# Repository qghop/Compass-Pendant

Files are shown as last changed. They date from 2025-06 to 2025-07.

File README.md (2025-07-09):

# Compass-Pendant
WIP - Creating a Pendant with LEDs and a Compass Module on a custom PCB

## Design Goals and Inspiration

The main design goal from the beginning was to create a unique piece of jewlery, from a Custom PCB with real-world functional components. 

Several purposes were ideated for this purpose. I initially wanted to create a GPS Logging Device to track my position, an idea I was first enamored by with [BOTW's Hero's Path Mode](https://www.youtube.com/watch?v=YSooSC6LfSU), and without giving my position data away to, or relying upon, a huge company like Google Maps' Timeline feature requires. I couldn't figure out a way to keep all the components small for this idea, so it was shelved, though I implemented a similar feature in my [Apple Photos Analysis Project](https://github.com/qghop/Apple-Photos-Analysis).

Different sensors, chips, and general designs were considered, but eventually using a Coin Cell Battery, an ATmega328P, and an I2C Magnetometer were chosen for ease of implementing, in both wiring and programming. 

The whole project was heavily inspired by the work of [Mitxela](https://mitxela.com/), especially his [UV Protection Amulet](https://www.youtube.com/watch?v=JhNMeJZ8Ll0) and [Fluid Simulation Pendant](https://www.youtube.com/watch?v=jis1MC5Tm8k). The header for chip programming was taken from the [KeyChainino](https://www.keychainino.com/) project, thanks to [upir](https://www.youtube.com/watch?v=Zsum_6dWfVU) for their video on the device. Additional thanks to the hundreds of KiCad tutorials used to build the PCB.

## Media

### V1

Working Compass Video (https://www.youtube.com/watch?v=5i10F70vsIM)

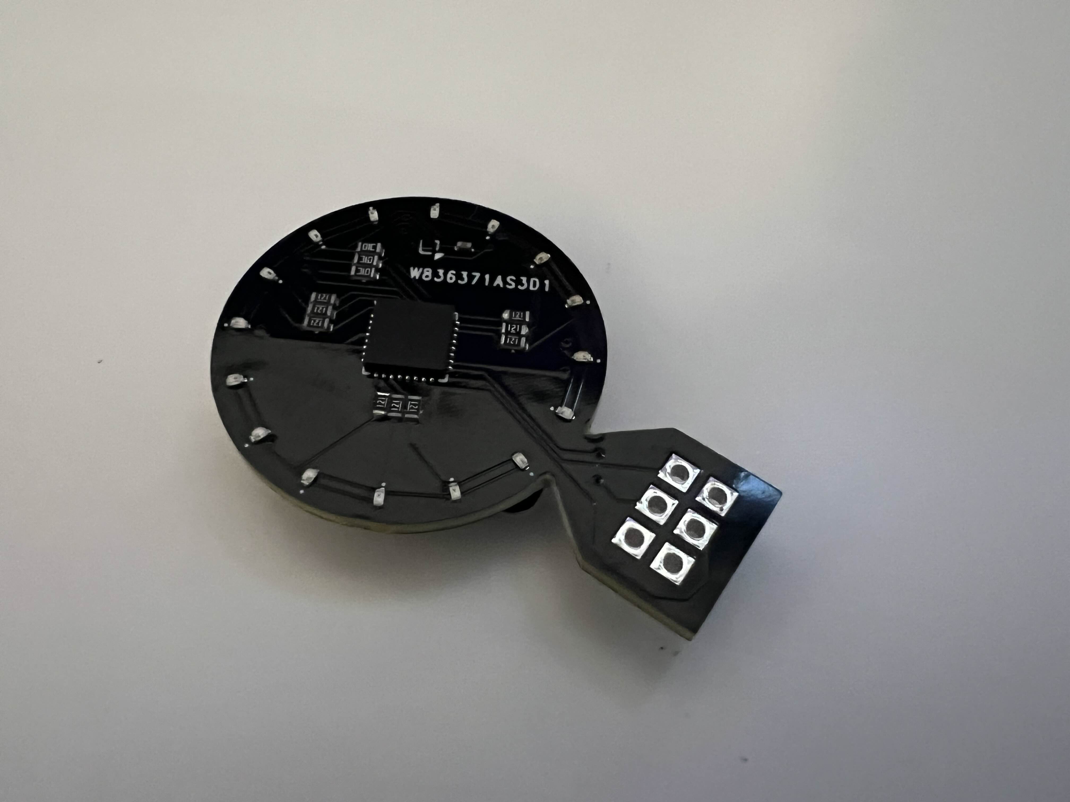
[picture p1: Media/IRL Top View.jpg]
Top View


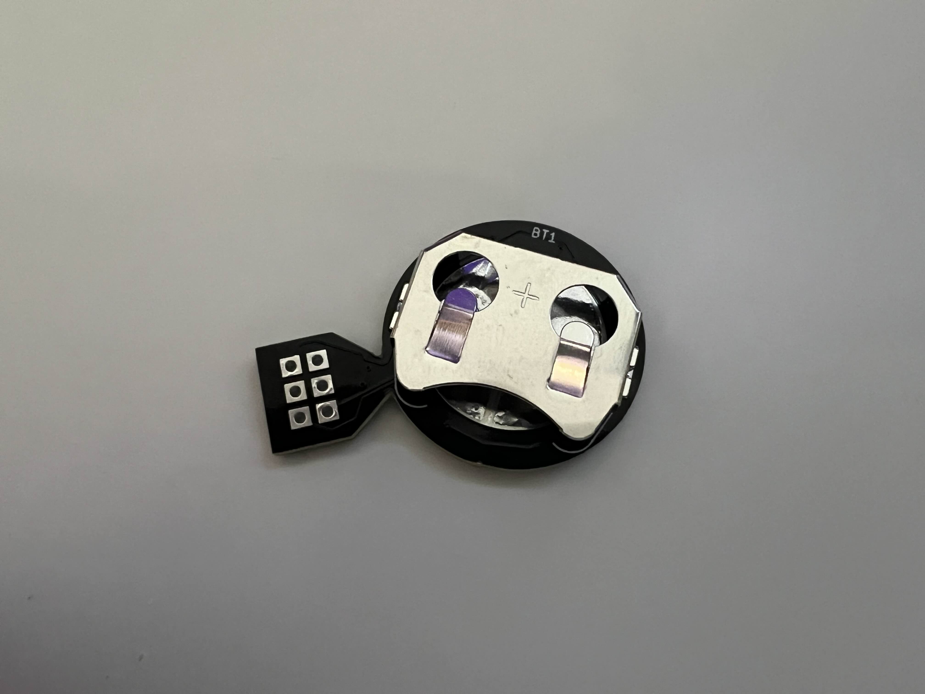
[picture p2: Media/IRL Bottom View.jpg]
Bottom View


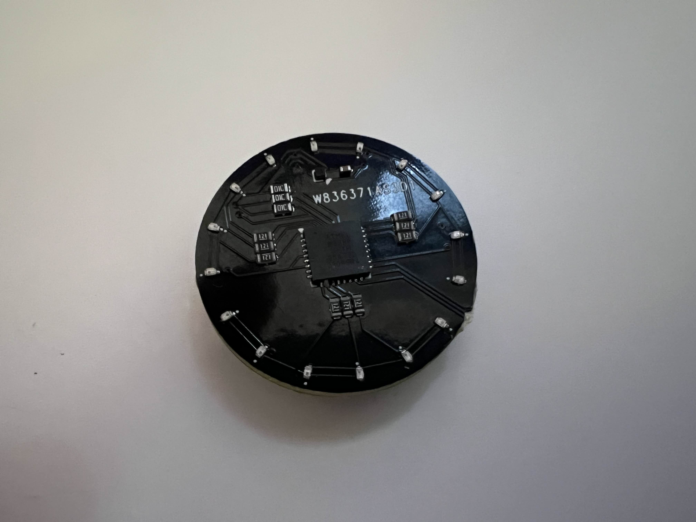
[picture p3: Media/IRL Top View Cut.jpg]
Top View, Cut


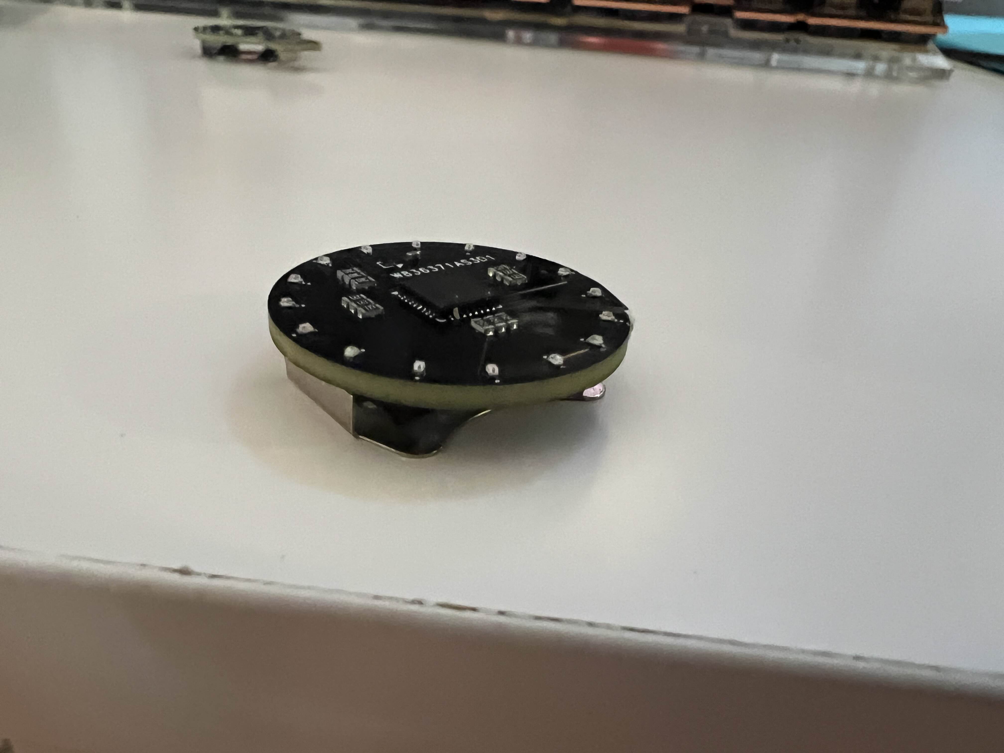
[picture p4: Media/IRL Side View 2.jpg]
Side View


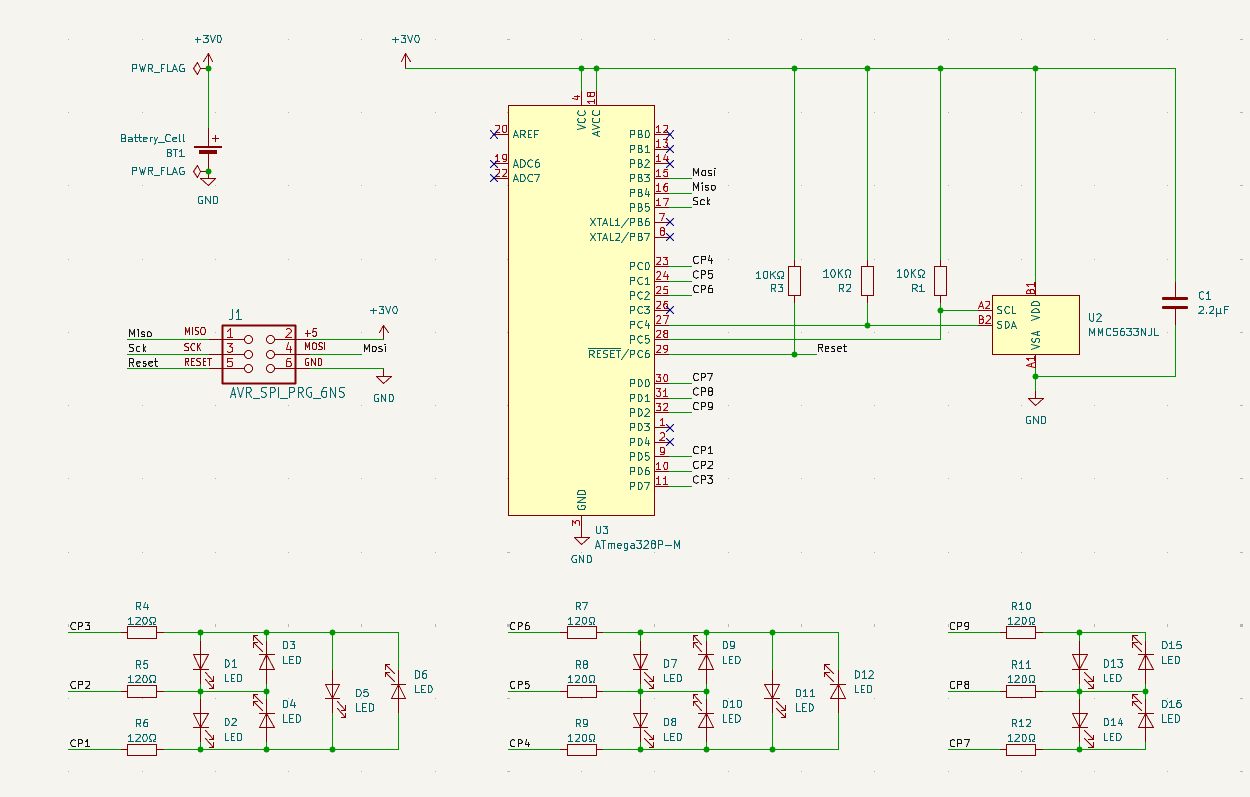
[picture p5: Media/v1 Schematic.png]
Schematic


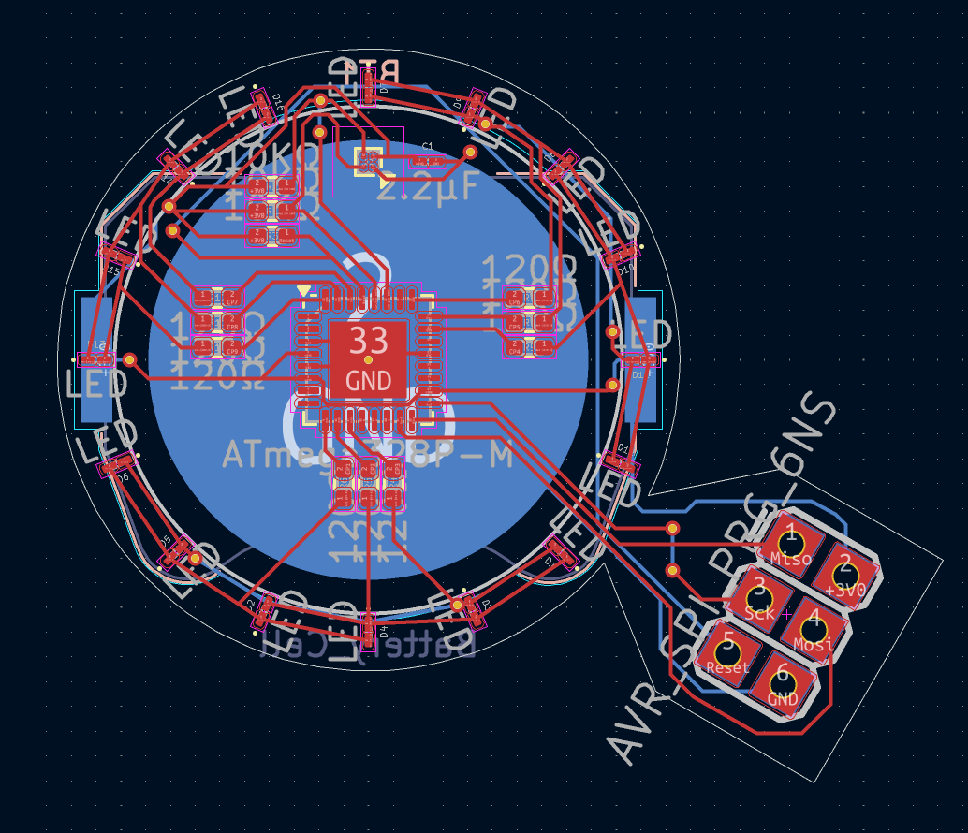
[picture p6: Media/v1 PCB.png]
PCB


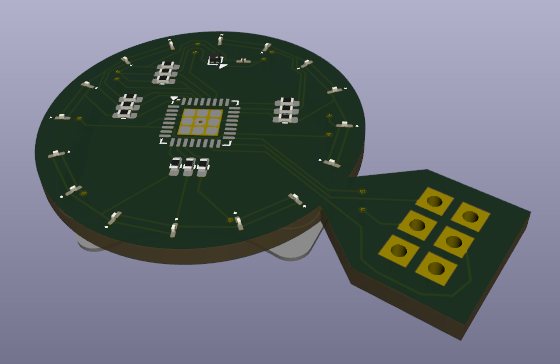
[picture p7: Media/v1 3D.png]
3D Model


Programming Video (https://www.youtube.com/watch?v=YMhp7EAuIT4)

## V1 Successes

Honestly, I was suprised by how not difficult this project was. Obviously I have a very basic scope, but to have my PCB design work, essentially, first try, is remarkable as someone with only the base electrical experience required of a Mechanical Engineering grad. KiCad especially proved to be quite easy to learn.

A functional V1 device was created!

## V1 Failures

- A switch was initially considered, but was removed to more easily wire connections with the large battery pads taking most of the limited space. This was a mistake, a switch is really required for actual use. Removing the battery from the chosen holder is not easy, and a case for the PCB (which could hide the LEDs) would add a ton of complexity, and would cover up an, in my opinion, great looking bare PCB.

- The battery is oddly inconsistent in delivering power to the magnetometer. This problem needs to be properly diagnosed, but there is no issue in running the debug "BasicSpinningLights.ino" sketch, but there is sometimes issues with the Compass program loaded.

- PCBA is too expensive to justify for revisions, so V2 should be designed so I could assemble myself (mostly meaning larger components).

- The small, red LEDs aren't as appealing as envisioned. Could be fixed with a diffuser, a larger or variable resistor, or a cooler (blue, green) color.

- The snap-off header could be designed to be easier to cut off, or designed to be integrated into the jewlery, as say the part that connects to the necklace chain.

## Programming

I primarily referenced the [KeyChainino Guide](https://www.keychainino.com/how-to-program-keychainino-v144-via-isp/) for programming. Below is a summarized version, with some tweaks.

1. Install the MiniCore Library to the Arduino IDE.

2. Load the example sketch "ArduinoISP" to the Arduino UNO.

3. Remove the battery from the Pendant, and don't put it back in until finished. Physically connect the Pendant programming header to the proper pins of the UNO. 

    This can be done via wiring:

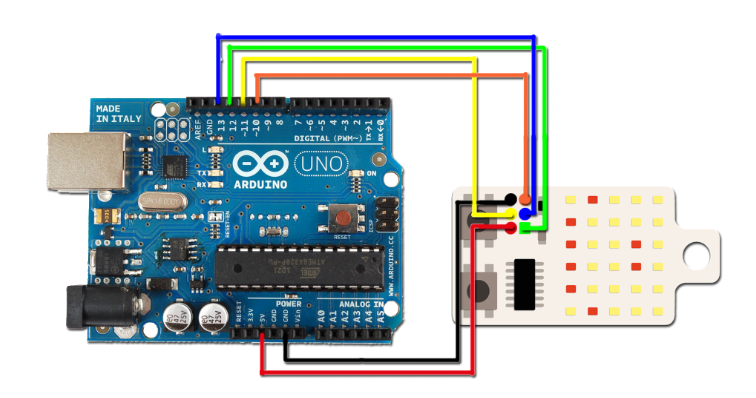
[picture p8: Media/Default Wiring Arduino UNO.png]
Default Wiring Programming Method
    

    Or via the ISP header of the UNO. The RESET pin of the ISP pins cannot be used though, so there must still be one manual connection to Digital Pin 10, acting as a digital reset:

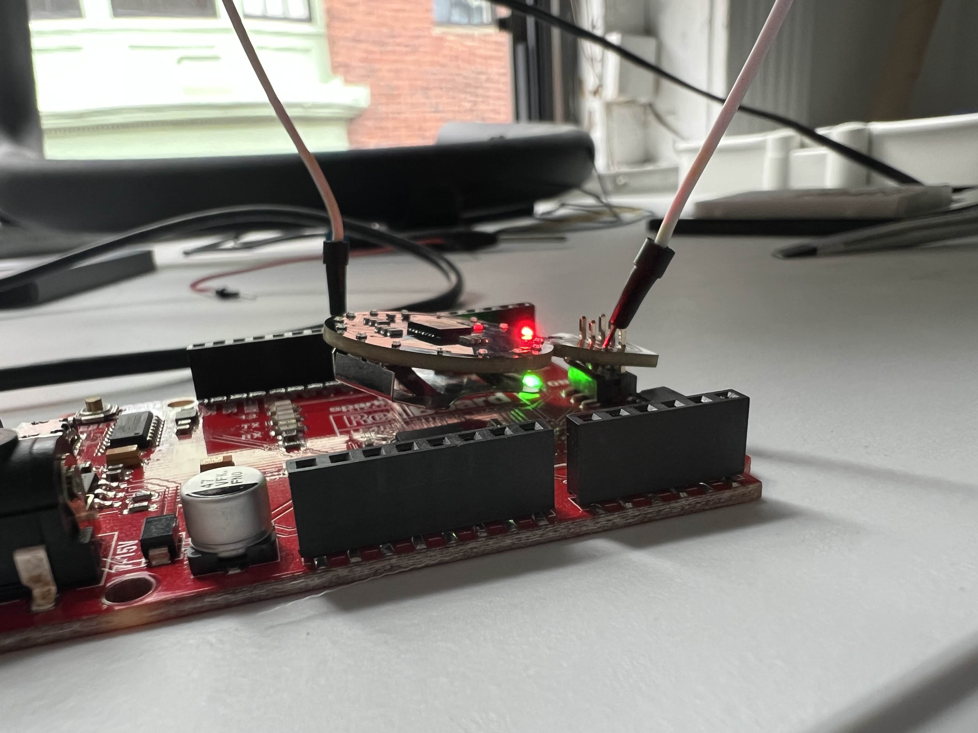
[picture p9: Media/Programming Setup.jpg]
Header Programming 1
    

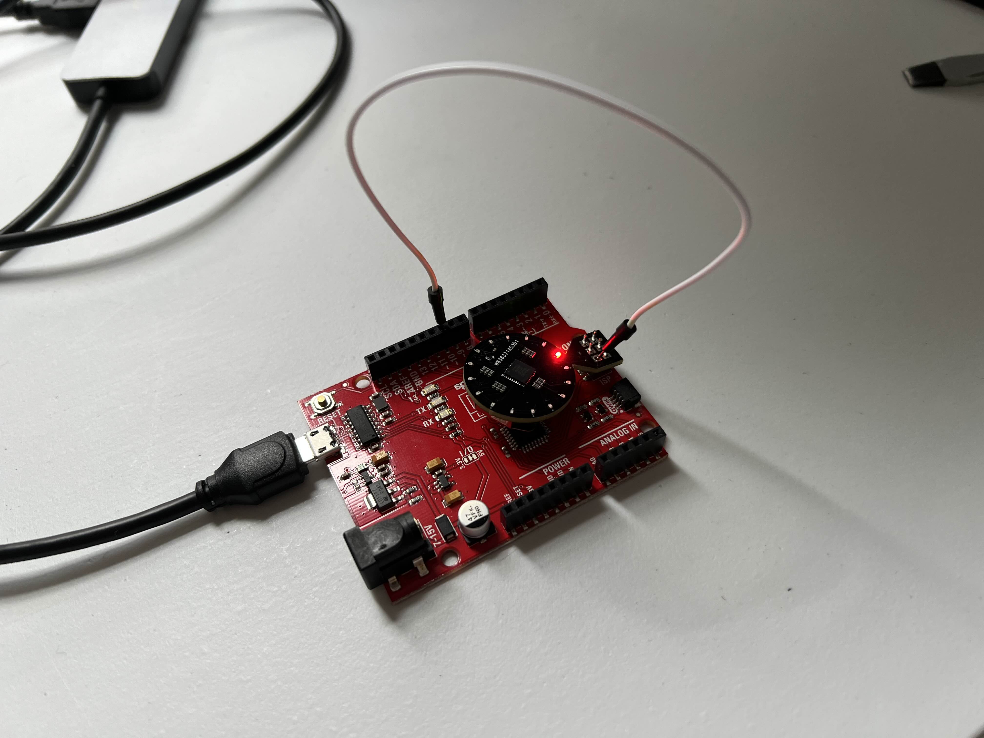
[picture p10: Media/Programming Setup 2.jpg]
Header Programming 2
    

4. Switch to the ATmega328 Board, with the following settings:

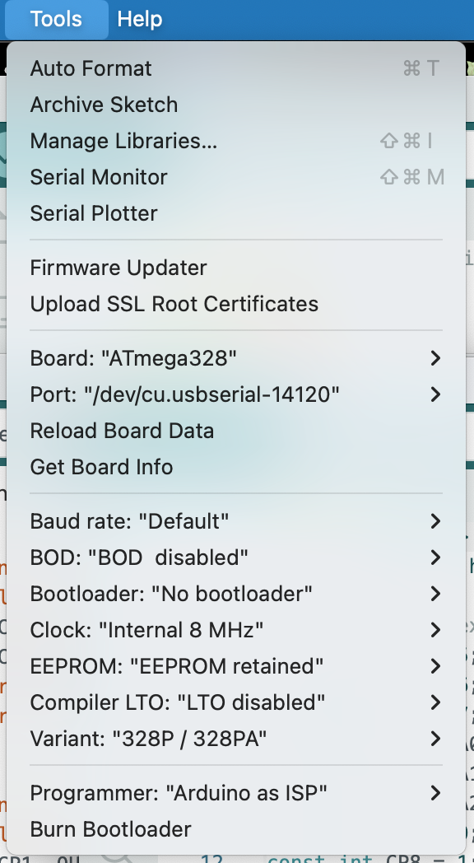
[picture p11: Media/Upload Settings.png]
Upload Settings


5. If first time programming the chip, run "Burn Bootloader" from Tools

6. Upload the sketch. If errors occour, wires are likely not connected properly. Tilting the pendant or the wires can help ensure connection.

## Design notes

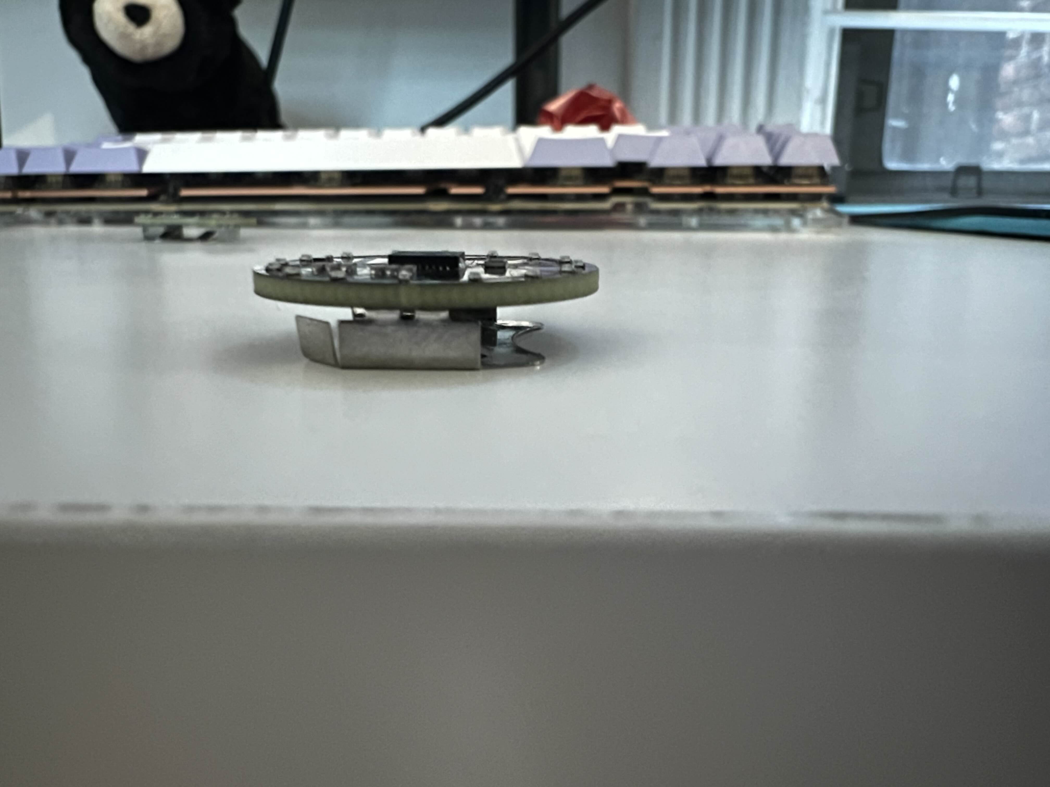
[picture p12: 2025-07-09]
Media/IRL Side View.jpg

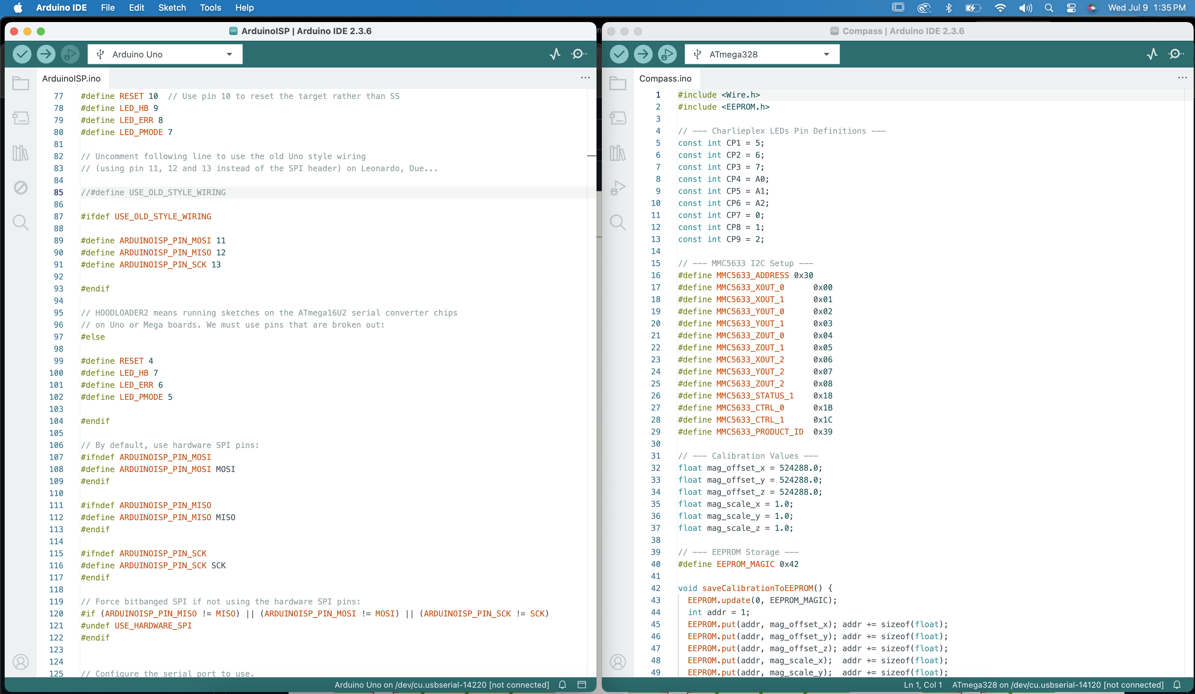
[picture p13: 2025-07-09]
Media/Arduino IDE View.png

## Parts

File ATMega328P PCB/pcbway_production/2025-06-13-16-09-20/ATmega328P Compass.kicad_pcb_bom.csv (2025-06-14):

Designator | Quantity | Value | Footprint | Package | MPN | DNP | Mount_Type | Description | Sim.Pins
BT1 | 1 | Battery_Cell | BatteryHolder_Keystone_3034_1x20mm | - | 3034TR |  | smt | Single-cell battery
C1 | 1 | 2.2µF | C_01005_0402Metric_Pad0.57x0.30mm_HandSolder | 0402 | CL05A225MQ5NSNC |  | smt | Unpolarized capacitor
D1, D10, D11, D12, D13, D14, D15, D16, D2, D3, D4, D5, D6, D7, D8, D9 | 16 | LED | LED_01005_0402Metric_Pad0.57x0.30mm_HandSolder | 0402 | BL-HUB37A-AV-TRB |  | smt | Light emitting diode | 1=K 2=A
R1, R2, R3 | 3 | 10KΩ | R_0402_1005Metric_Pad0.72x0.64mm_HandSolder | 0402 | 0402WGF1002TCE |  | smt | Resistor
R10, R11, R12, R4, R5, R6, R7, R8, R9 | 9 | 120Ω | R_0402_1005Metric_Pad0.72x0.64mm_HandSolder | 0402 | 0402WGF1200TCE |  | smt | Resistor
U2 | 1 | MMC5633NJL | WLP-4_0.86x0.86mm_P0.4mm | WLP-4(0.9x0.9) | MMC5633NJL |  | smt | 3-axis AMR Magnetometer, 30 G, I2C & I3C Interface, 2mG RMS, WLP-4
U3 | 1 | ATmega328P-M | QFN-32-1EP_5x5mm_P0.5mm_EP3.1x3.1mm | VQFN-32_5x5 | ATMEGA328P-MU |  | smt | 20MHz, 32kB Flash, 2kB SRAM, 1kB EEPROM, QFN-32

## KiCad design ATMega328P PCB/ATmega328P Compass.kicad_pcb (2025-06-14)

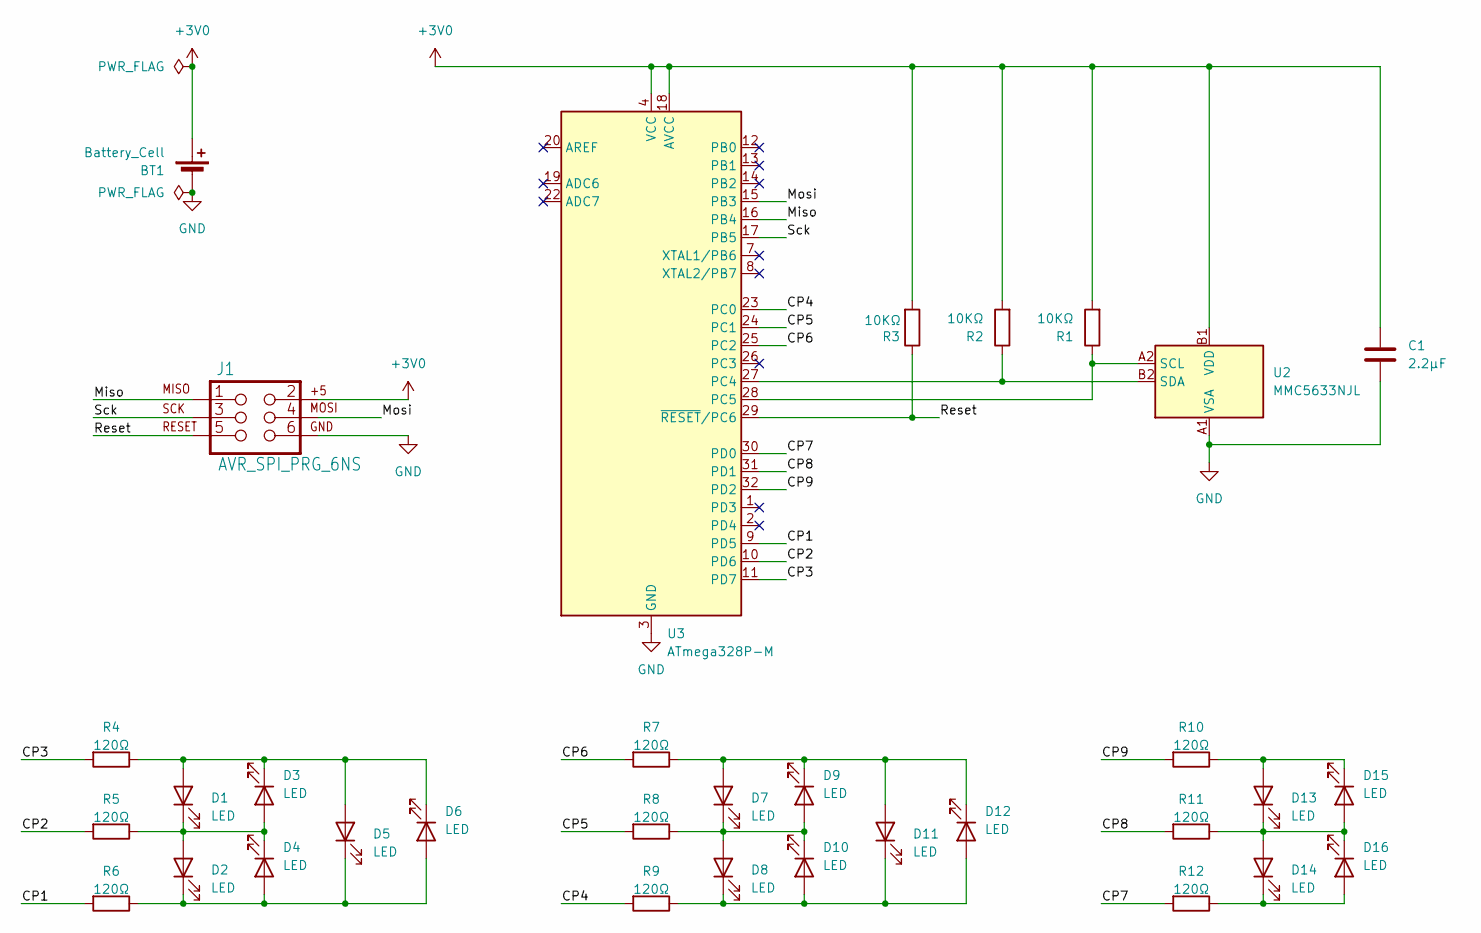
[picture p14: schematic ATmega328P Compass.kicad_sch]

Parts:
BT1: Battery_Cell; BatteryHolder_Keystone_3034_1x20mm
C1: 2.2µF; C_01005_0402Metric_Pad0.57x0.30mm_HandSolder
D1, D2, D3, D4, D5, D6, D7, D8, D9, D10, D11, D12, D13, D14, D15, D16: LED; LED_01005_0402Metric_Pad0.57x0.30mm_HandSolder
J1: AVR_SPI_PRG_6NS; 2X3-NS
R1, R2, R3: 10KΩ; R_0402_1005Metric_Pad0.72x0.64mm_HandSolder
R4, R5, R6, R7, R8, R9, R10, R11, R12: 120Ω; R_0402_1005Metric_Pad0.72x0.64mm_HandSolder
U2: MMC5633NJL; WLP-4_0.86x0.86mm_P0.4mm
U3: ATmega328P-M; QFN-32-1EP_5x5mm_P0.5mm_EP3.1x3.1mm

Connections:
+3V0: BT1.1 (+), C1.1, J1.2, R1.2, R2.2, R3.2, U2.B1 (VDD), U3.4 (VCC), U3.6 (VCC), U3.18 (AVCC)
/CP1: R6.2, U3.9 (PD5)
/CP2: R5.2, U3.10 (PD6)
/CP3: R4.2, U3.11 (PD7)
/CP4: R9.2, U3.23 (PC0)
/CP5: R8.2, U3.24 (PC1)
/CP6: R7.2, U3.25 (PC2)
/CP7: R12.2, U3.30 (PD0)
/CP8: R11.2, U3.31 (PD1)
/CP9: R10.2, U3.32 (PD2)
/Miso: J1.1, U3.16 (PB4)
/Mosi: J1.4, U3.15 (PB3)
/Reset: J1.5, R3.1, U3.29 (~RESET/PC6)
/Sck: J1.3, U3.17 (PB5)
GND: BT1.2 (-), C1.2, J1.6, U2.A1 (VSA), U3.3 (GND), U3.5 (GND), U3.21 (GND), U3.33 (GND)
unnamed: D1.2 (A), D3.1 (K), D5.2 (A), D6.1 (K), R4.1
unnamed: D1.1 (K), D2.2 (A), D3.2 (A), D4.1 (K), R5.1
unnamed: D2.1 (K), D4.2 (A), D5.1 (K), D6.2 (A), R6.1
unnamed: D8.1 (K), D10.2 (A), D11.1 (K), D12.2 (A), R9.1
unnamed: D7.1 (K), D8.2 (A), D9.2 (A), D10.1 (K), R8.1
unnamed: D7.2 (A), D9.1 (K), D11.2 (A), D12.1 (K), R7.1
unnamed: D13.2 (A), D15.1 (K), R10.1
unnamed: D13.1 (K), D14.2 (A), D15.2 (A), D16.1 (K), R11.1
unnamed: D14.1 (K), D16.2 (A), R12.1
unnamed: R1.1, U2.A2 (SCL), U3.28 (PC5)
unnamed: R2.1, U2.B2 (SDA), U3.27 (PC4)

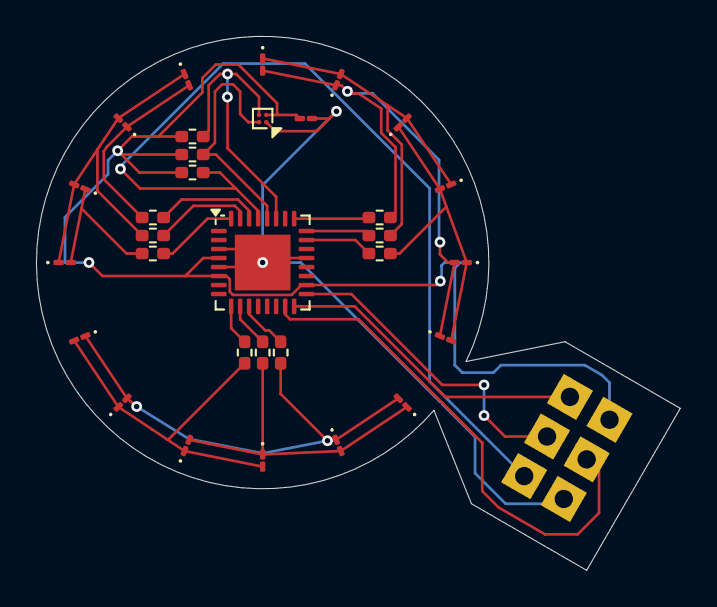
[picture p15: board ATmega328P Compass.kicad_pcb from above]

Board: 2 copper layers, 35.8 x 29.7 mm, 33 parts (1 on the bottom side), 26 nets.

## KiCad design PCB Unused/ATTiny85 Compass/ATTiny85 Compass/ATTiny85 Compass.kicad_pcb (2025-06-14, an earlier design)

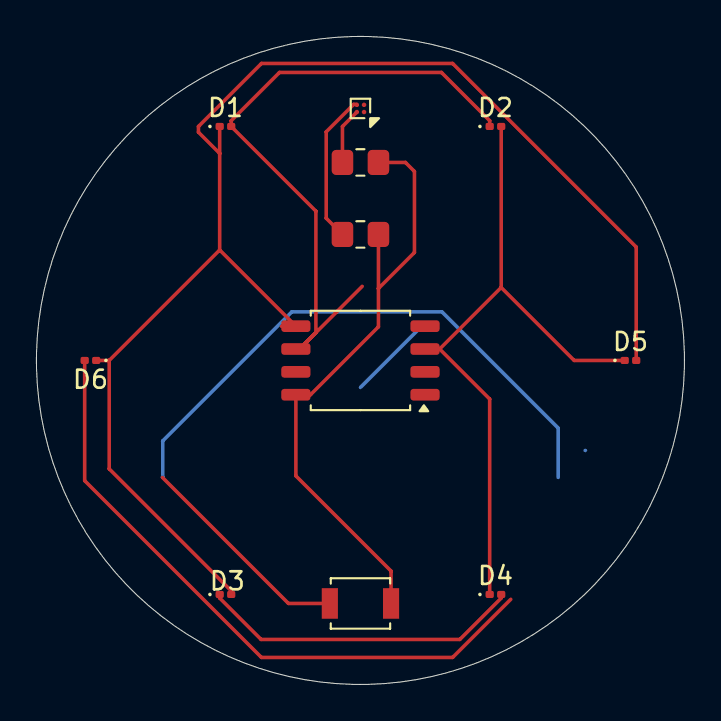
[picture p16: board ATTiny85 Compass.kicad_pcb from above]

Board: 2 copper layers, 36.0 x 36.0 mm, 12 parts (1 on the bottom side), 8 nets.

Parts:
BT1: Battery_Cell; BatteryHolder_Keystone_3034_1x20mm
D1, D2, D3, D4, D5, D6: LED; LED_0201_0603Metric
R1, R2: 10Kohm; R_0805_2012Metric_Pad1.20x1.40mm_HandSolder
SW1: SW_SPST; SW_SPST_B3U-1000P
U2: MMC5633NJL; WLP-4_0.86x0.86mm_P0.4mm
U3: ATtiny85-20S; SOIC-8_5.3x5.3mm_P1.27mm

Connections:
unnamed: BT1.1 (+), SW1.1 (A)
unnamed: BT1.2 (-), U2.A1 (VSA), U3.4 (GND)
unnamed: D1.2 (A), D2.1 (K), D3.1 (K), D4.2 (A), U3.6 (PB1)
unnamed: D1.1 (K), D3.2 (A), D5.2 (A), D6.1 (K), U3.5 (AREF/PB0)
unnamed: D2.2 (A), D4.1 (K), D5.1 (K), D6.2 (A), U3.3 (XTAL2/PB4)
unnamed: R1.2, R2.2, SW1.2 (B), U2.B1 (VDD), U3.8 (VCC)
unnamed: R1.1, U2.A2 (SCL), U3.7 (PB2)
unnamed: R2.1, U2.B2 (SDA), U3.2 (XTAL1/PB3)

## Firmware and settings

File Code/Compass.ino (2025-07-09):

#include <Wire.h>
#include <EEPROM.h>

// --- Charlieplex LEDs Pin Definitions ---
const int CP1 = 5;
const int CP2 = 6;
const int CP3 = 7;
const int CP4 = A0;
const int CP5 = A1;
const int CP6 = A2;
const int CP7 = 0;
const int CP8 = 1;
const int CP9 = 2;

// --- MMC5633 I2C Setup ---
#define MMC5633_ADDRESS 0x30
#define MMC5633_XOUT_0      0x00
#define MMC5633_XOUT_1      0x01
#define MMC5633_YOUT_0      0x02
#define MMC5633_YOUT_1      0x03
#define MMC5633_ZOUT_0      0x04
#define MMC5633_ZOUT_1      0x05
#define MMC5633_XOUT_2      0x06
#define MMC5633_YOUT_2      0x07
#define MMC5633_ZOUT_2      0x08
#define MMC5633_STATUS_1    0x18
#define MMC5633_CTRL_0      0x1B
#define MMC5633_CTRL_1      0x1C
#define MMC5633_PRODUCT_ID  0x39

// --- Calibration Values ---
float mag_offset_x = 524288.0;
float mag_offset_y = 524288.0;
float mag_offset_z = 524288.0;
float mag_scale_x = 1.0;
float mag_scale_y = 1.0;
float mag_scale_z = 1.0;

// --- EEPROM Storage ---
#define EEPROM_MAGIC 0x42

void saveCalibrationToEEPROM() {
  EEPROM.update(0, EEPROM_MAGIC);
  int addr = 1;
  EEPROM.put(addr, mag_offset_x); addr += sizeof(float);
  EEPROM.put(addr, mag_offset_y); addr += sizeof(float);
  EEPROM.put(addr, mag_offset_z); addr += sizeof(float);
  EEPROM.put(addr, mag_scale_x);  addr += sizeof(float);
  EEPROM.put(addr, mag_scale_y);  addr += sizeof(float);
  EEPROM.put(addr, mag_scale_z);  addr += sizeof(float);
}

bool loadCalibrationFromEEPROM() {
  if (EEPROM.read(0) != EEPROM_MAGIC) return false;
  int addr = 1;
  EEPROM.get(addr, mag_offset_x); addr += sizeof(float);
  EEPROM.get(addr, mag_offset_y); addr += sizeof(float);
  EEPROM.get(addr, mag_offset_z); addr += sizeof(float);
  EEPROM.get(addr, mag_scale_x);  addr += sizeof(float);
  EEPROM.get(addr, mag_scale_y);  addr += sizeof(float);
  EEPROM.get(addr, mag_scale_z);  addr += sizeof(float);
  return true;
}

// --- Magnetometer ---
bool initMagnetometer() {
  Wire.begin();
  delay(20);
  Wire.beginTransmission(MMC5633_ADDRESS);
  Wire.write(MMC5633_PRODUCT_ID);
  if (Wire.endTransmission() != 0) return false;
  Wire.requestFrom(MMC5633_ADDRESS, 1);
  if (!Wire.available()) return false;
  if (Wire.read() != 0x10) return false;

  Wire.beginTransmission(MMC5633_ADDRESS);
  Wire.write(MMC5633_CTRL_1);
  Wire.write(0x80); // Soft reset
  Wire.endTransmission();
  delay(20);

  Wire.beginTransmission(MMC5633_ADDRESS);
  Wire.write(MMC5633_CTRL_0);
  Wire.write(0x20); // Auto_SR_en
  Wire.endTransmission();
  delay(1);
  return true;
}

bool readRawMagnetometer(uint32_t &x, uint32_t &y, uint32_t &z) {
  Wire.beginTransmission(MMC5633_ADDRESS);
  Wire.write(MMC5633_CTRL_0);
  Wire.write(0b00100001);
  Wire.endTransmission();

  unsigned long start = millis();
  while (millis() - start < 20) {
    Wire.beginTransmission(MMC5633_ADDRESS);
    Wire.write(MMC5633_STATUS_1);
    Wire.endTransmission();
    Wire.requestFrom(MMC5633_ADDRESS, 1);
    if (Wire.available() && (Wire.read() & 0b01000000)) break;
    delay(2);
  }

  uint8_t data[9];
  Wire.beginTransmission(MMC5633_ADDRESS);
  Wire.write(MMC5633_XOUT_0);
  Wire.endTransmission();
  if (Wire.requestFrom(MMC5633_ADDRESS, 6) != 6) return false;
  for (int i = 0; i < 6; i++) data[i] = Wire.read();

  Wire.beginTransmission(MMC5633_ADDRESS);
  Wire.write(MMC5633_XOUT_2);
  Wire.endTransmission();
  if (Wire.requestFrom(MMC5633_ADDRESS, 3) != 3) return false;
  for (int i = 0; i < 3; i++) data[i + 6] = Wire.read();

  x = ((uint32_t)data[0] << 12) | ((uint32_t)data[1] << 4) | (data[6] >> 4);
  y = ((uint32_t)data[2] << 12) | ((uint32_t)data[3] << 4) | (data[7] >> 4);
  z = ((uint32_t)data[4] << 12) | ((uint32_t)data[5] << 4) | (data[8] >> 4);
  return true;
}

// --- Calibrate and Store ---
void calibrateMagnetometer() {
  uint32_t min_x = 0xFFFFFFFF, max_x = 0;
  uint32_t min_y = 0xFFFFFFFF, max_y = 0;
  uint32_t min_z = 0xFFFFFFFF, max_z = 0;

  unsigned long startTime = millis();
  // originally 30000 seconds, now 15000
  while (millis() - startTime < 15000) {
    uint32_t x, y, z;
    if (readRawMagnetometer(x, y, z)) {
      min_x = min(min_x, x); max_x = max(max_x, x);
      min_y = min(min_y, y); max_y = max(max_y, y);
      min_z = min(min_z, z); max_z = max(max_z, z);
    }
    delay(50);
  }

  mag_offset_x = (max_x + min_x) / 2.0;
  mag_offset_y = (max_y + min_y) / 2.0;
  mag_offset_z = (max_z + min_z) / 2.0;

  float range_x = max_x - min_x;
  float range_y = max_y - min_y;
  float avg_range = (range_x + range_y) / 2.0;

  mag_scale_x = avg_range / range_x;
  mag_scale_y = avg_range / range_y;
  mag_scale_z = 1.0;
}

// --- Get North ---
float getCompassHeading() {
  uint32_t raw_x, raw_y, raw_z;

  if (readRawMagnetometer(raw_x, raw_y, raw_z)) {
    // Apply calibration values to raw data before calculating heading
    float calibrated_x = ((float)raw_x - mag_offset_x) * mag_scale_x;
    float calibrated_y = ((float)raw_y - mag_offset_y) * mag_scale_y;
    
    // Calculate heading from the calibrated XY plane data.
    // atan2 handles all quadrants correctly.
    float heading = atan2(calibrated_y, calibrated_x) * 180.0 / PI;
    
    // Normalize to 0-360 degrees
    if (heading < 0) {
      heading += 360.0;
    }
    return heading;
  } else {
    return -1.0; // Error reading magnetometer
  }
}

float getNorthDirection() {
  float heading = getCompassHeading();
  if (heading < 0) {
    return -1.0; // Error
  }
  
  // The direction TO North is the opposite of our current heading.
  float northDirection = 360.0 - heading;
  if (northDirection >= 360.0) {
      northDirection -= 360.0;
  }
  
  return northDirection;
}

void showNorthDirection() {
  float northDirection = getNorthDirection();
  
  if (northDirection < 0) {
    // Indicate an error by flashing an LED
    turnOnD7();
    delay(200);
    turnOffAllLEDs();
    delay(200);
    return;
  }

  // Shift the direction 90 degrees clockwise 
  // Quick fix, getNorthDirection gets direction of West for whatever reason
  northDirection += 90.0;
  if (northDirection >= 360.0) northDirection -= 360.0;
  
  // Convert degrees to LED index (16 LEDs = 22.5° each).
  // Add 11.25deg offset for proper rounding to the nearest LED.
  int ledIndex = (int)((northDirection + 11.25) / 22.5) % 16;
  
  switch(ledIndex) {
    case 0:  turnOnD7(); break;  // N
    case 1:  turnOnD9(); break;  // NNE
    case 2:  turnOnD8(); break;  // NE
    case 3:  turnOnD10(); break; // ENE
    case 4:  turnOnD11(); break; // E
    case 5:  turnOnD12(); break; // ESE
    case 6:  turnOnD1(); break;  // SE
    case 7:  turnOnD3(); break;  // SSE
    case 8:  turnOnD4(); break;  // S
    case 9:  turnOnD2(); break;  // SSW
    case 10: turnOnD5(); break; // SW
    case 11: turnOnD6(); break; // WSW
    case 12: turnOnD13(); break;// W
    case 13: turnOnD15(); break;// WNW
    case 14: turnOnD14(); break;// NW
    case 15: turnOnD16(); break;// NNW
    default: turnOffAllLEDs(); break;
  }
}

// --- LED Control Functions ---
void turnOffAllLEDs() {
  pinMode(CP1, INPUT);
  pinMode(CP2, INPUT);
  pinMode(CP3, INPUT);
  pinMode(CP4, INPUT);
  pinMode(CP5, INPUT);
  pinMode(CP6, INPUT);
  pinMode(CP7, INPUT);
  pinMode(CP8, INPUT);
  pinMode(CP9, INPUT);
}

void turnOnD1() {
  turnOffAllLEDs();
  pinMode(CP3, OUTPUT);
  pinMode(CP2, OUTPUT);
  digitalWrite(CP3, HIGH);
  digitalWrite(CP2, LOW);
}

void turnOnD2() {
  turnOffAllLEDs();
  pinMode(CP2, OUTPUT);
  pinMode(CP1, OUTPUT);
  digitalWrite(CP2, HIGH);
  digitalWrite(CP1, LOW);
}

void turnOnD3() {
  turnOffAllLEDs();
  pinMode(CP2, OUTPUT);
  pinMode(CP3, OUTPUT);
  digitalWrite(CP2, HIGH);
  digitalWrite(CP3, LOW);
}

void turnOnD4() {
  turnOffAllLEDs();
  pinMode(CP1, OUTPUT);
  pinMode(CP2, OUTPUT);
  digitalWrite(CP1, HIGH);
  digitalWrite(CP2, LOW);
}

void turnOnD5() {
  turnOffAllLEDs();
  pinMode(CP3, OUTPUT);
  pinMode(CP1, OUTPUT);
  digitalWrite(CP3, HIGH);
  digitalWrite(CP1, LOW);
}

void turnOnD6() {
  turnOffAllLEDs();
  pinMode(CP1, OUTPUT);
  pinMode(CP3, OUTPUT);
  digitalWrite(CP1, HIGH);
  digitalWrite(CP3, LOW);
}

void turnOnD7() {
  turnOffAllLEDs();
  pinMode(CP6, OUTPUT);
  pinMode(CP5, OUTPUT);
  digitalWrite(CP6, HIGH);
  digitalWrite(CP5, LOW);
}

void turnOnD8() {
  turnOffAllLEDs();
  pinMode(CP5, OUTPUT);
  pinMode(CP4, OUTPUT);
  digitalWrite(CP5, HIGH);
  digitalWrite(CP4, LOW);
}

void turnOnD9() {
  turnOffAllLEDs();
  pinMode(CP5, OUTPUT);
  pinMode(CP6, OUTPUT);
  digitalWrite(CP5, HIGH);
  digitalWrite(CP6, LOW);
}

void turnOnD10() {
  turnOffAllLEDs();
  pinMode(CP4, OUTPUT);
  pinMode(CP5, OUTPUT);
  digitalWrite(CP4, HIGH);
  digitalWrite(CP5, LOW);
}

void turnOnD11() {
  turnOffAllLEDs();
  pinMode(CP6, OUTPUT);
  pinMode(CP4, OUTPUT);
  digitalWrite(CP6, HIGH);
  digitalWrite(CP4, LOW);
}

void turnOnD12() {
  turnOffAllLEDs();
  pinMode(CP4, OUTPUT);
  pinMode(CP6, OUTPUT);
  digitalWrite(CP4, HIGH);
  digitalWrite(CP6, LOW);
}

void turnOnD13() {
  turnOffAllLEDs();
  pinMode(CP9, OUTPUT);
  pinMode(CP8, OUTPUT);
  digitalWrite(CP9, HIGH);
  digitalWrite(CP8, LOW);
}

void turnOnD14() {
  turnOffAllLEDs();
  pinMode(CP8, OUTPUT);
  pinMode(CP7, OUTPUT);
  digitalWrite(CP8, HIGH);
  digitalWrite(CP7, LOW);
}

void turnOnD15() {
  turnOffAllLEDs();
  pinMode(CP8, OUTPUT);
  pinMode(CP9, OUTPUT);
  digitalWrite(CP8, HIGH);
  digitalWrite(CP9, LOW);
}

void turnOnD16() {
  turnOffAllLEDs();
  pinMode(CP7, OUTPUT);
  pinMode(CP8, OUTPUT);
  digitalWrite(CP7, HIGH);
  digitalWrite(CP8, LOW);
}

void cycleThroughAllLEDs() {
  int delayTime = 200;
  turnOnD7(); delay(delayTime);
  turnOnD9(); delay(delayTime);
  turnOnD8(); delay(delayTime);
  turnOnD10(); delay(delayTime);
  turnOnD11(); delay(delayTime);
  turnOnD12(); delay(delayTime);
  turnOnD1(); delay(delayTime);
  turnOnD3(); delay(delayTime);
  turnOnD4(); delay(delayTime);
  turnOnD2(); delay(delayTime);
  turnOnD5(); delay(delayTime);
  turnOnD6(); delay(delayTime);
  turnOnD13(); delay(delayTime);
  turnOnD15(); delay(delayTime);
  turnOnD14(); delay(delayTime);
  turnOnD16(); delay(delayTime);
  turnOffAllLEDs();
}

void calibrationSignal() {
  turnOffAllLEDs();
  for (int i = 0; i <= 2; i++) {
    turnOnD7(); delay(200);
    turnOnD11(); delay(200);
    turnOnD4(); delay(200);
    turnOnD13(); delay(200);
  }
  turnOffAllLEDs();
}

// --- Setup ---
void setup() {
  pinMode(CP1, INPUT);
  pinMode(CP2, INPUT);
  pinMode(CP3, INPUT);
  pinMode(CP4, INPUT);
  pinMode(CP5, INPUT);
  pinMode(CP6, INPUT);
  pinMode(CP7, INPUT);
  pinMode(CP8, INPUT);
  pinMode(CP9, INPUT);

  if (!initMagnetometer()) {
    // Magnetometer failed to initialize, cycle LEDs
    while(1) {
      cycleThroughAllLEDs();
    };
  }

  // If no calibration data in EEPROM, run calibration
  if (!loadCalibrationFromEEPROM()) {
    calibrationSignal();
    calibrateMagnetometer();
    saveCalibrationToEEPROM();
    calibrationSignal();
  }
}

void loop() {
  showNorthDirection();
  delay(50);
}

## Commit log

2025-06-14 Uploading PCB 1
    Uploading ATMega328P PCB (First PCB sent to PCBWay) and previous attempts/ideas with ATTiny85+84
    [ATTiny85 Compass.kicad_pcb, ATTiny85 Compass.kicad_sch, ATmega328P Compass Too Big.kicad_pcb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]
2025-07-08 Basic LED control code
2025-07-09 Added media, code from working device
